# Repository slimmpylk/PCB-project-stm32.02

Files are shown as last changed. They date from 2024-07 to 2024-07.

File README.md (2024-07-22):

# Project Overview

The primary goal of this project was to intricately design the electronics and circuit board for a sophisticated embedded device. By harnessing our team's deep technical expertise, we set out to develop a high-end wireless weather station. This system is powered by the STM32WB microcontroller, renowned for its high performance and reliability in handling wireless communications.

## Implementation Details

Our team is committed to providing a comprehensive solution that not only measures various environmental parameters accurately but also facilitates efficient data transmission through wireless networks. At the heart of our design, the STM32WB microcontroller boasts Bluetooth capabilities, making it an excellent choice for our advanced weather monitoring system.

## Key Features

- **Real-Time Environmental Monitoring:** The station is capable of measuring temperature and humidity.
- **Energy-Efficient Design:** Focuses on low power consumption, ideal for long-term deployment in remote areas with minimal maintenance requirements.

This project is a testament to our team's dedication to pushing the boundaries of innovation and excellence in embedded systems design.

## Pics

# PCB
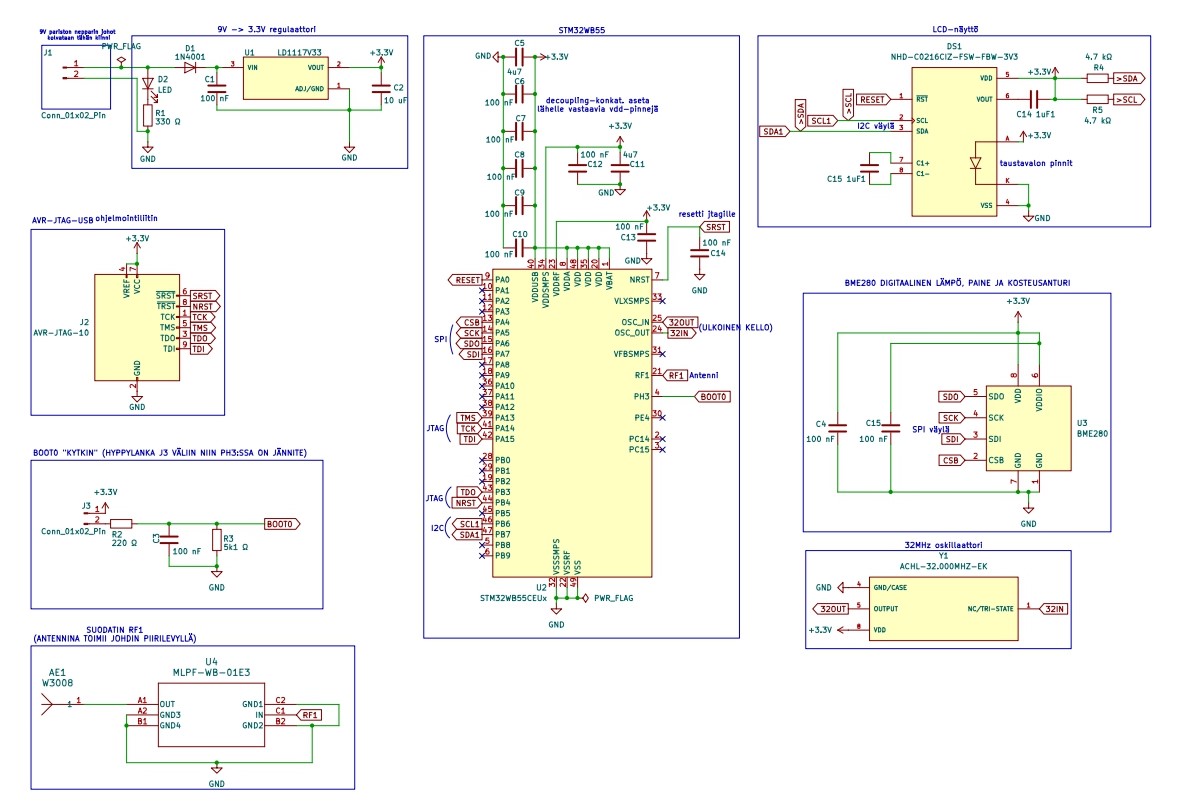
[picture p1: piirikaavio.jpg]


# PCB-schema
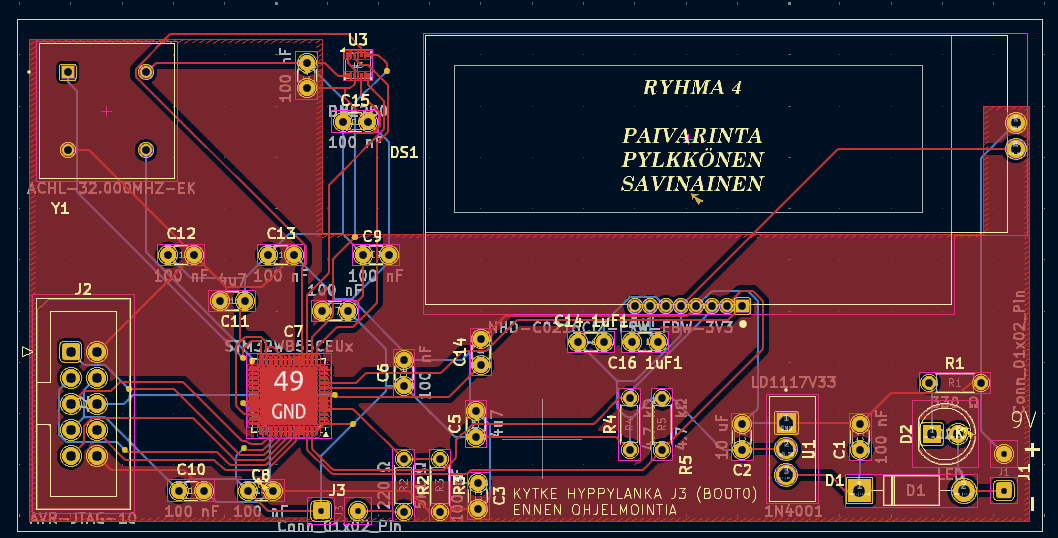
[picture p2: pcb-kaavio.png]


# 3D-pic
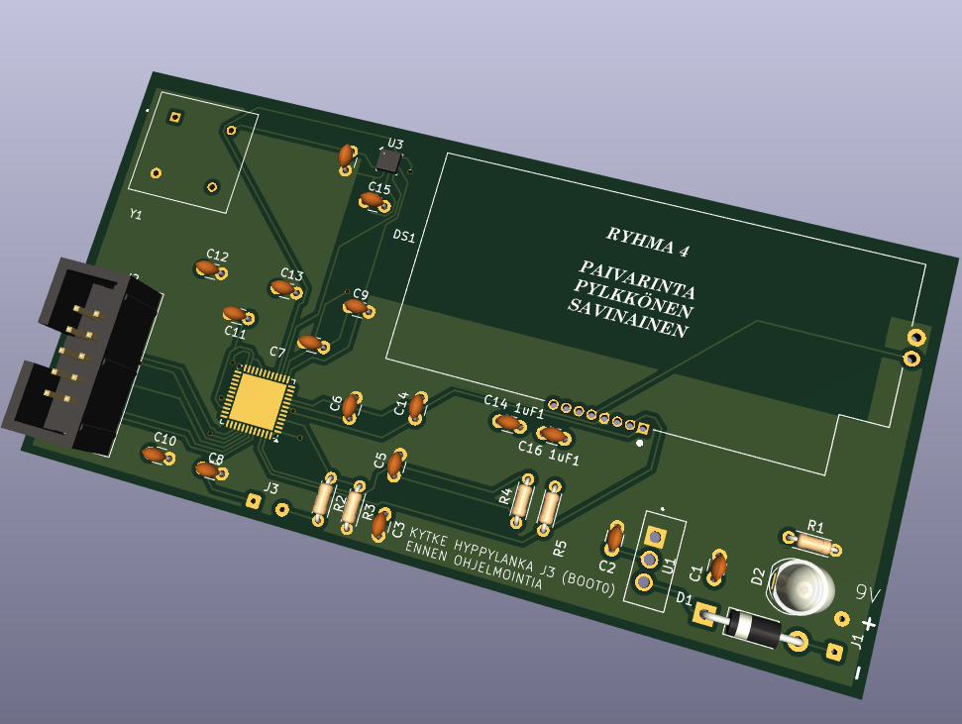
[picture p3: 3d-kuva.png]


# Built PCB
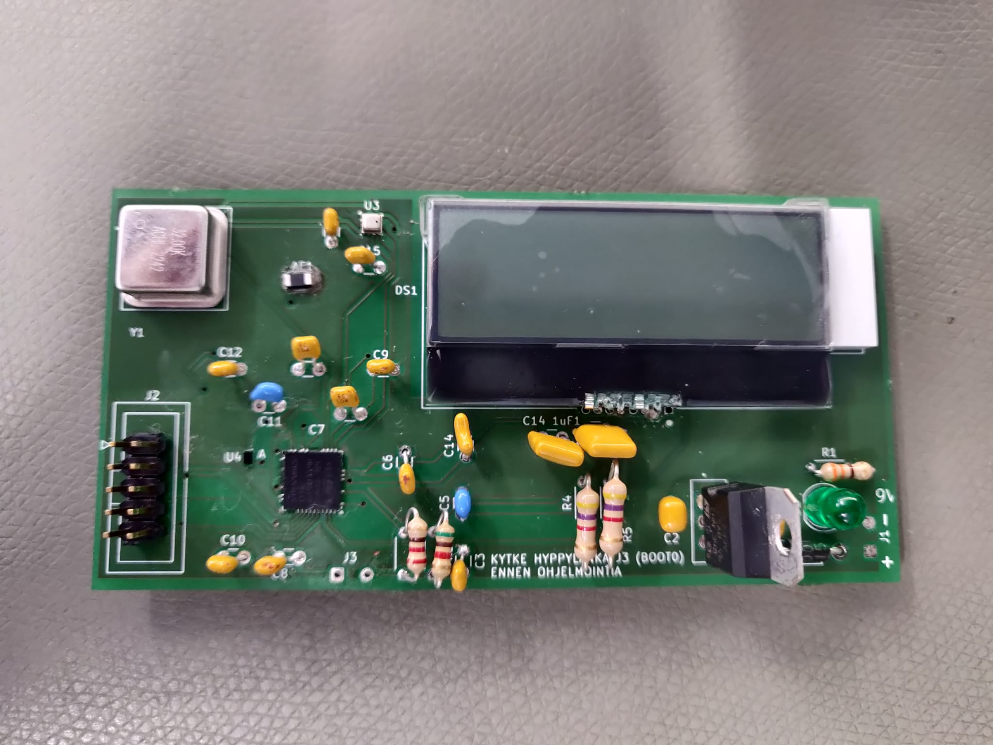
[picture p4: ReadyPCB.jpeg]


# STM close-up
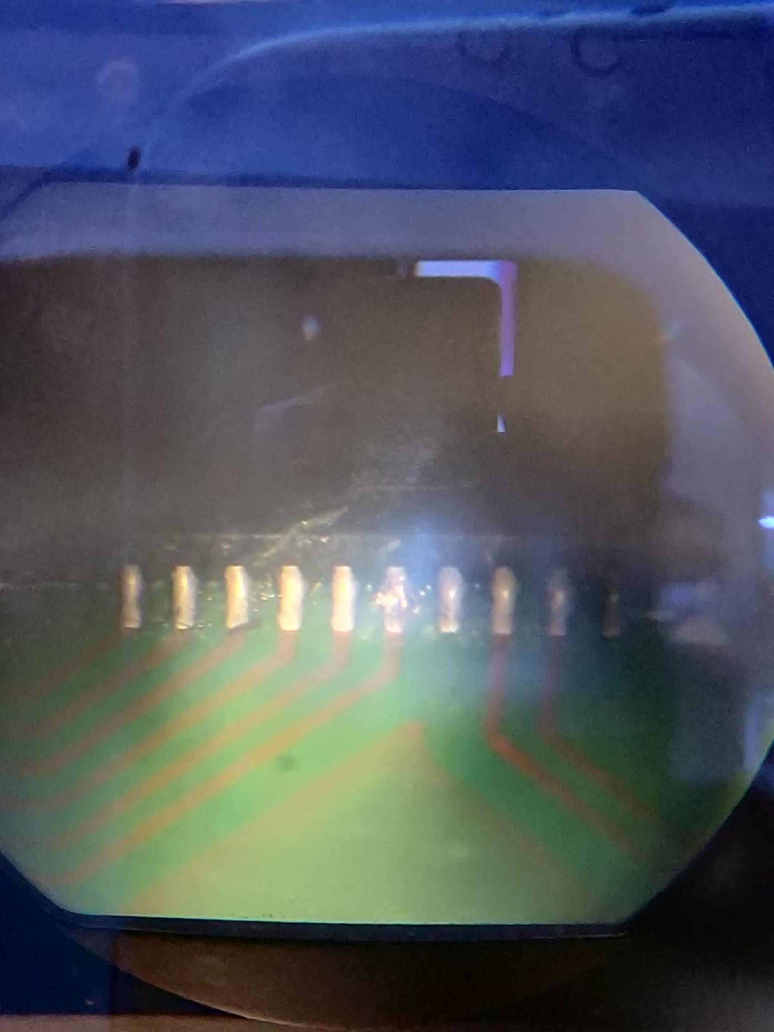
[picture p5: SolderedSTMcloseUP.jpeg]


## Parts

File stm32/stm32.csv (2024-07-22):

Source: | C:\Users\sammi\Desktop\kevätprojekti\Kevat24Proj\stm32\stm32.kicad_sch
Date: | 2024-04-04T11:24:38+0300
Tool: | Eeschema 8.0.1
Generator: | C:\Users\sammi\AppData\Local\Programs\KiCad\8.0\bin\scripting\plugins/bom_csv_grouped_by_value_with_fp.py
Component Count: | 34
Ref | Qnty | Value | Cmp name | Footprint | Description | Vendor | DNP
AE1 | 1 | W3008 | W3008 | footprints:ANT_W3008_PUL
C1, C3, C4, C6, C7, C8, C9, C10, C12, C13, C14, C15 | 12 | 100 nF | C | Capacitor_THT:C_Disc_D3.0mm_W1.6mm_P2.50mm | Unpolarized capacitor
C2 | 1 | 10 uF | C | Capacitor_THT:C_Disc_D3.0mm_W1.6mm_P2.50mm | Unpolarized capacitor
C5, C11 | 2 | 4u7 | C | Capacitor_THT:C_Disc_D3.0mm_W1.6mm_P2.50mm | Unpolarized capacitor
C14 1uF1 | 1 | ~ | C | Capacitor_THT:C_Disc_D3.0mm_W1.6mm_P2.50mm | Unpolarized capacitor
C15 1uF1 | 1 | 1uF | C | Capacitor_THT:C_Disc_D3.0mm_W1.6mm_P2.50mm | Unpolarized capacitor
D1 | 1 | 1N4001 | 1N4001 | Diode_THT:D_DO-41_SOD81_P10.16mm_Horizontal | 50V 1A General Purpose Rectifier Diode, DO-41
D2 | 1 | LED | LED | LED_THT:LED_D5.0mm_Clear | Light emitting diode
DS1 | 1 | NHD-C0216CIZ-FSW-FBW-3V3 | NHD-C0216CIZ-FSW-FBW-3V3 | lcd:LCD_NHD-C0216CIZ-FSW-FBW-3V3 | Character Display FSTN Transflective 16Char x 2Line 8-Pin
J1, J3 | 2 | Conn_01x02_Pin | Conn_01x02_Pin | Connector_Wire:SolderWire-0.1sqmm_1x02_P3.6mm_D0.4mm_OD1mm | Generic connector, single row, 01x02, script generated
J2 | 1 | AVR-JTAG-10 | AVR-JTAG-10 | Connector_IDC:IDC-Header_2x05_P2.54mm_Vertical | Atmel 10-pin JTAG connector
R1 | 1 | 330 Ω | R | Resistor_THT:R_Axial_DIN0204_L3.6mm_D1.6mm_P5.08mm_Horizontal | Resistor
R2 | 1 | 220 Ω | R | Resistor_THT:R_Axial_DIN0204_L3.6mm_D1.6mm_P5.08mm_Horizontal | Resistor
R3 | 1 | 5k1 Ω | R | Resistor_THT:R_Axial_DIN0204_L3.6mm_D1.6mm_P5.08mm_Horizontal | Resistor
R4, R5 | 2 | 4.7 kΩ | R | Resistor_THT:R_Axial_DIN0204_L3.6mm_D1.6mm_P5.08mm_Horizontal | Resistor
U1 | 1 | LD1117V33 | LD1117V33 | rekulaattori:TO255P1020X450X1968-3
U2 | 1 | STM32WB55CEUx | STM32WB55CEUx | Package_DFN_QFN:QFN-48-1EP_7x7mm_P0.5mm_EP5.6x5.6mm | STMicroelectronics Arm Cortex-M4 MCU, 512KB flash, 256KB RAM, 64 MHz, 1.71-3.6V, 30 GPIO, UFQFPN48
U3 | 1 | BME280 | BME280 | Package_LGA:Bosch_LGA-8_2.5x2.5mm_P0.65mm_ClockwisePinNumbering | 3-in-1 sensor, humidity, pressure, temperature, I2C and SPI interface, 1.71-3.6V, LGA-8
U4 | 1 | MLPF-WB-01E3 | MLPF-WB-01E3 | lpf:CSP6_BUMPLESS_STM
Y1 | 1 | ACHL-32.000MHZ-EK | ACHL-32.000MHZ-EK | oskillaattori:XTAL_ACHL-32.000MHZ-EK

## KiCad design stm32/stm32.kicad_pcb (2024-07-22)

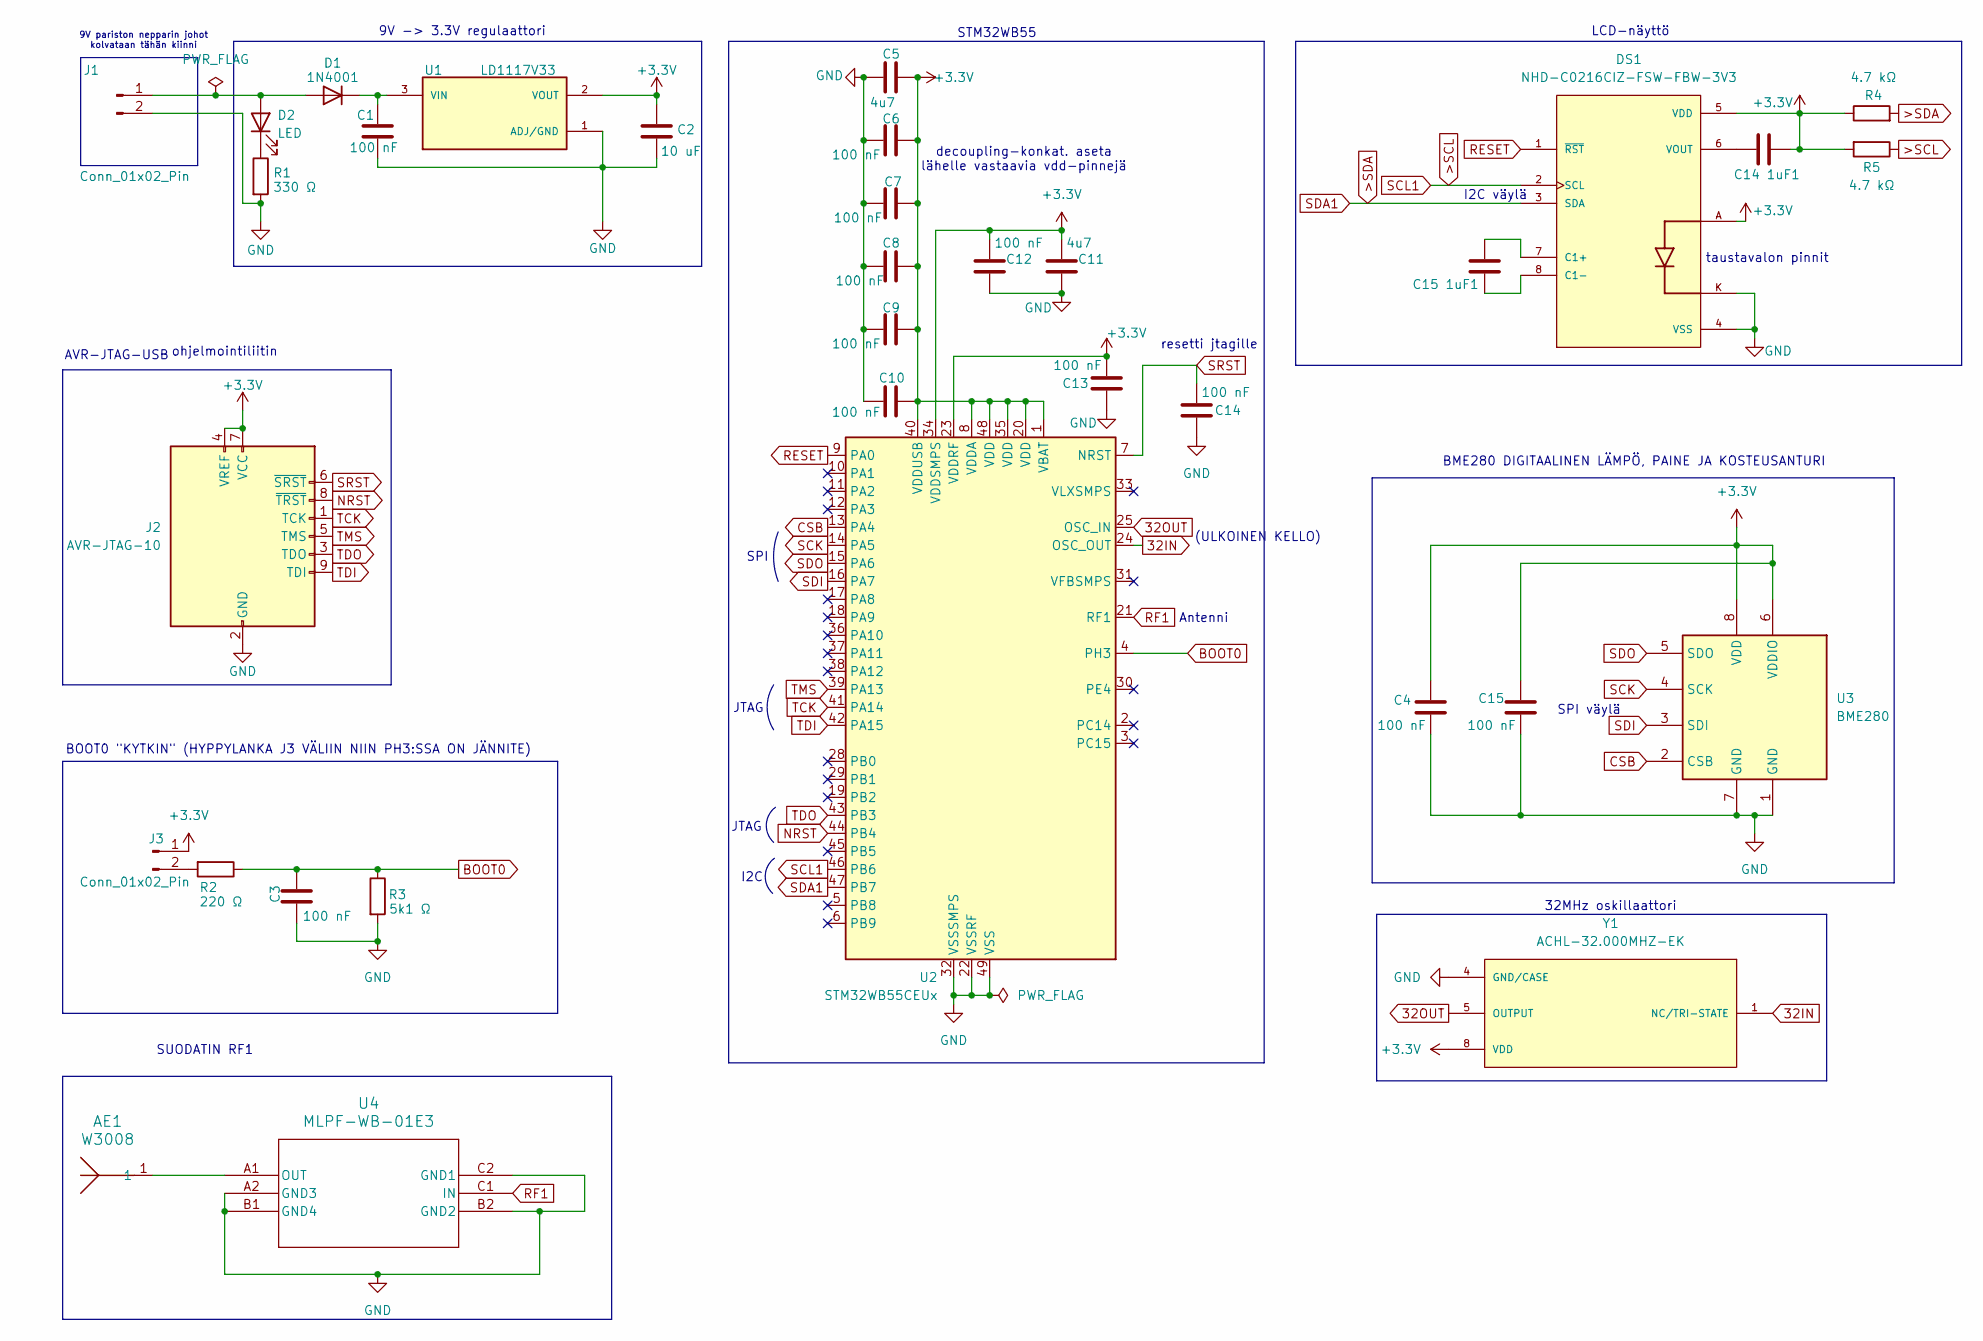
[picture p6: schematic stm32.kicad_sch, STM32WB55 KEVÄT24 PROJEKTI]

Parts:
AE1: W3008; ANT_W3008_PUL
C1, C3, C4, C6, C7, C8, C9, C10, C12, C13, C14, C15: 100 nF; C_Disc_D3.0mm_W1.6mm_P2.50mm
C2: 10 uF; C_Disc_D3.0mm_W1.6mm_P2.50mm
C5, C11: 4u7; C_Disc_D3.0mm_W1.6mm_P2.50mm
C14 1uF1: C_Disc_D3.0mm_W1.6mm_P2.50mm
C15 1uF1: 1uF; C_Disc_D3.0mm_W1.6mm_P2.50mm
D1: 1N4001; D_DO-41_SOD81_P10.16mm_Horizontal
D2: LED; LED_D5.0mm_Clear
DS1: NHD-C0216CIZ-FSW-FBW-3V3; LCD_NHD-C0216CIZ-FSW-FBW-3V3; PARTREV 6/4/19
J1, J3: Conn_01x02_Pin; SolderWire-0.1sqmm_1x02_P3.6mm_D0.4mm_OD1mm
J2: AVR-JTAG-10; IDC-Header_2x05_P2.54mm_Vertical
R1: 330 Ω; R_Axial_DIN0204_L3.6mm_D1.6mm_P5.08mm_Horizontal
R2: 220 Ω; R_Axial_DIN0204_L3.6mm_D1.6mm_P5.08mm_Horizontal
R3: 5k1 Ω; R_Axial_DIN0204_L3.6mm_D1.6mm_P5.08mm_Horizontal
R4, R5: 4.7 kΩ; R_Axial_DIN0204_L3.6mm_D1.6mm_P5.08mm_Horizontal
U1: LD1117V33; TO255P1020X450X1968-3; PARTREV 37
U2: STM32WB55CEUx; QFN-48-1EP_7x7mm_P0.5mm_EP5.6x5.6mm
U3: BME280; Bosch_LGA-8_2.5x2.5mm_P0.65mm_ClockwisePinNumbering
U4: MLPF-WB-01E3; CSP6_BUMPLESS_STM
Y1: ACHL-32.000MHZ-EK; XTAL_ACHL-32.000MHZ-EK; PARTREV 01.20.16

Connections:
32IN: U2.24 (OSC_OUT), Y1.1 (NC/TRI-STATE)
32OUT: U2.25 (OSC_IN), Y1.5 (OUTPUT)
+3.3V: C2.1, C4.1, C5.1, C6.1, C7.1, C8.1, C9.1, C10.1, C11.1, C12.1, C13.1, C14 1uF1.1, C15.1, DS1.5 (VDD), DS1.A, J2.4 (VREF), J2.7 (VCC), J3.1, R4.1, R5.2, U1.2 (VOUT), U2.1 (VBAT), U2.8 (VDDA), U2.20 (VDD), U2.23 (VDDRF), U2.34 (VDDSMPS), U2.35 (VDD), U2.40 (VDDUSB), U2.48 (VDD), U3.6 (VDDIO), U3.8 (VDD), Y1.8 (VDD)
>SCL: DS1.2 (SCL), R5.1, U2.46 (PB6)
>SDA: DS1.3 (SDA), R4.2, U2.47 (PB7)
BOOT0: C3.1, R2.1, R3.1, U2.4 (PH3)
CSB: U2.13 (PA4), U3.2 (CSB)
GND: C1.2, C2.2, C3.2, C4.2, C5.2, C6.2, C7.2, C8.2, C9.2, C10.2, C11.2, C12.2, C13.2, C14.2, C15.2, DS1.4 (VSS), DS1.K, J1.2, J2.2 (GND), J2.10 (GND), R1.2, R3.2, U1.1 (ADJ/GND), U2.22 (VSSRF), U2.32 (VSSSMPS), U2.49 (VSS), U3.1 (GND), U3.7 (GND), U4.A2 (GND3), U4.B1 (GND4), U4.B2 (GND2), U4.C2 (GND1), Y1.4 (GND/CASE)
NRST: J2.8 (~TRST), U2.44 (PB4)
unnamed: D1.2 (A), D2.2 (A), J1.1
unnamed: C1.1, D1.1 (K), U1.3 (VIN)
unnamed: D2.1 (K), R1.1
unnamed: C15 1uF1.1, DS1.7 (C1+)
unnamed: C15 1uF1.2, DS1.8 (C1-)
unnamed: C14 1uF1.2, DS1.6 (VOUT)
unnamed: J3.2, R2.2
unnamed: AE1.1, U4.A1 (OUT)
RESET: DS1.1 (~RST), U2.9 (PA0)
RF1: U2.21 (RF1), U4.C1 (IN)
SCK: U2.14 (PA5), U3.4 (SCK)
SDI: U2.16 (PA7), U3.3 (SDI)
SDO: U2.15 (PA6), U3.5 (SDO)
SRST: C14.1, J2.6 (~SRST), U2.7 (NRST)
TCK: J2.1 (TCK), U2.41 (PA14)
TDI: J2.9 (TDI), U2.42 (PA15)
TDO: J2.3 (TDO), U2.43 (PB3)
TMS: J2.5 (TMS), U2.39 (PA13)

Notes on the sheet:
BME280 DIGITAALINEN LÄMPÖ, PAINE JA KOSTEUSANTURI
STM32WB55
Antenni
resetti jtagille
I2C väylä
decoupling-konkat. aseta lähelle vastaavia vdd-pinnejä
9V pariston nepparin johot kolvataan tähän kiinni
BOOT0 "KYTKIN" (HYPPYLANKA J3 VÄLIIN NIIN PH3:SSA ON JÄNNITE)
9V -> 3.3V regulaattori
JTAG
32MHz oskillaattori
AVR-JTAG-USB
I2C
SUODATIN RF1
(ULKOINEN KELLO)
LCD-näyttö
taustavalon pinnit
ohjelmointiliitin
SPI väylä
SPI

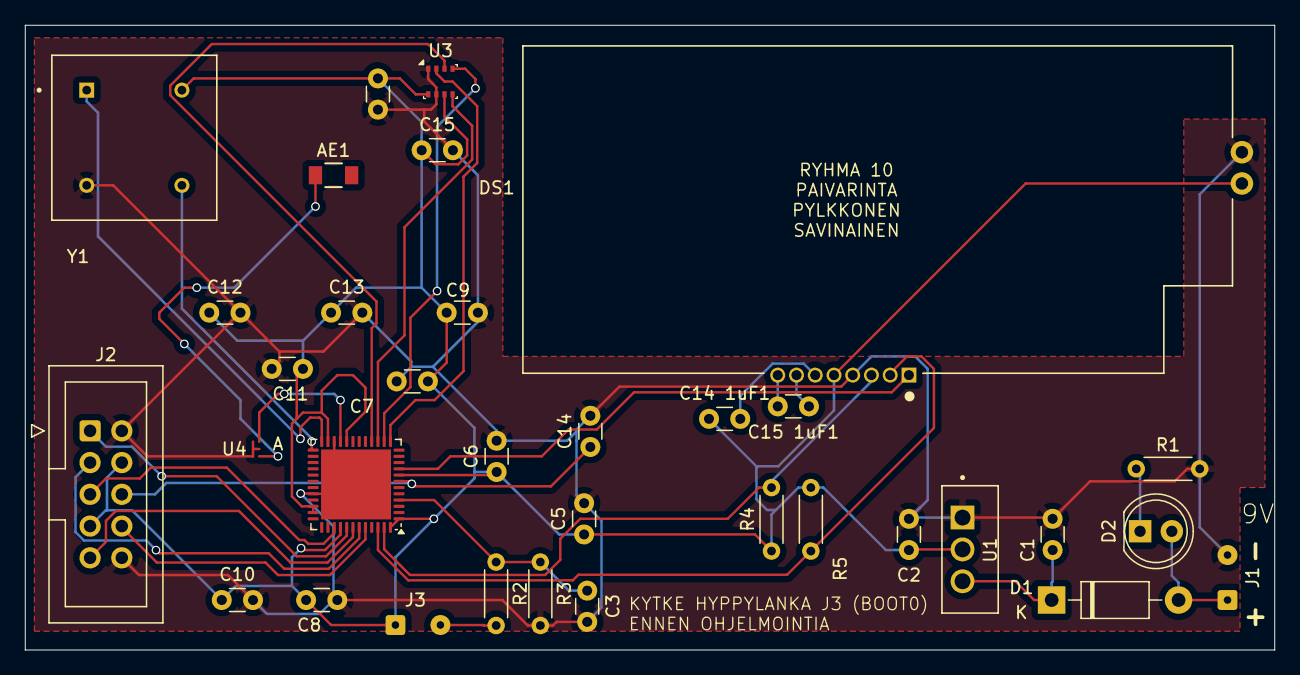
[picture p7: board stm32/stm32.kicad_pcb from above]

Board: 2 copper layers, 100.0 x 50.0 mm, 34 parts (0 on the bottom side), 27 nets.

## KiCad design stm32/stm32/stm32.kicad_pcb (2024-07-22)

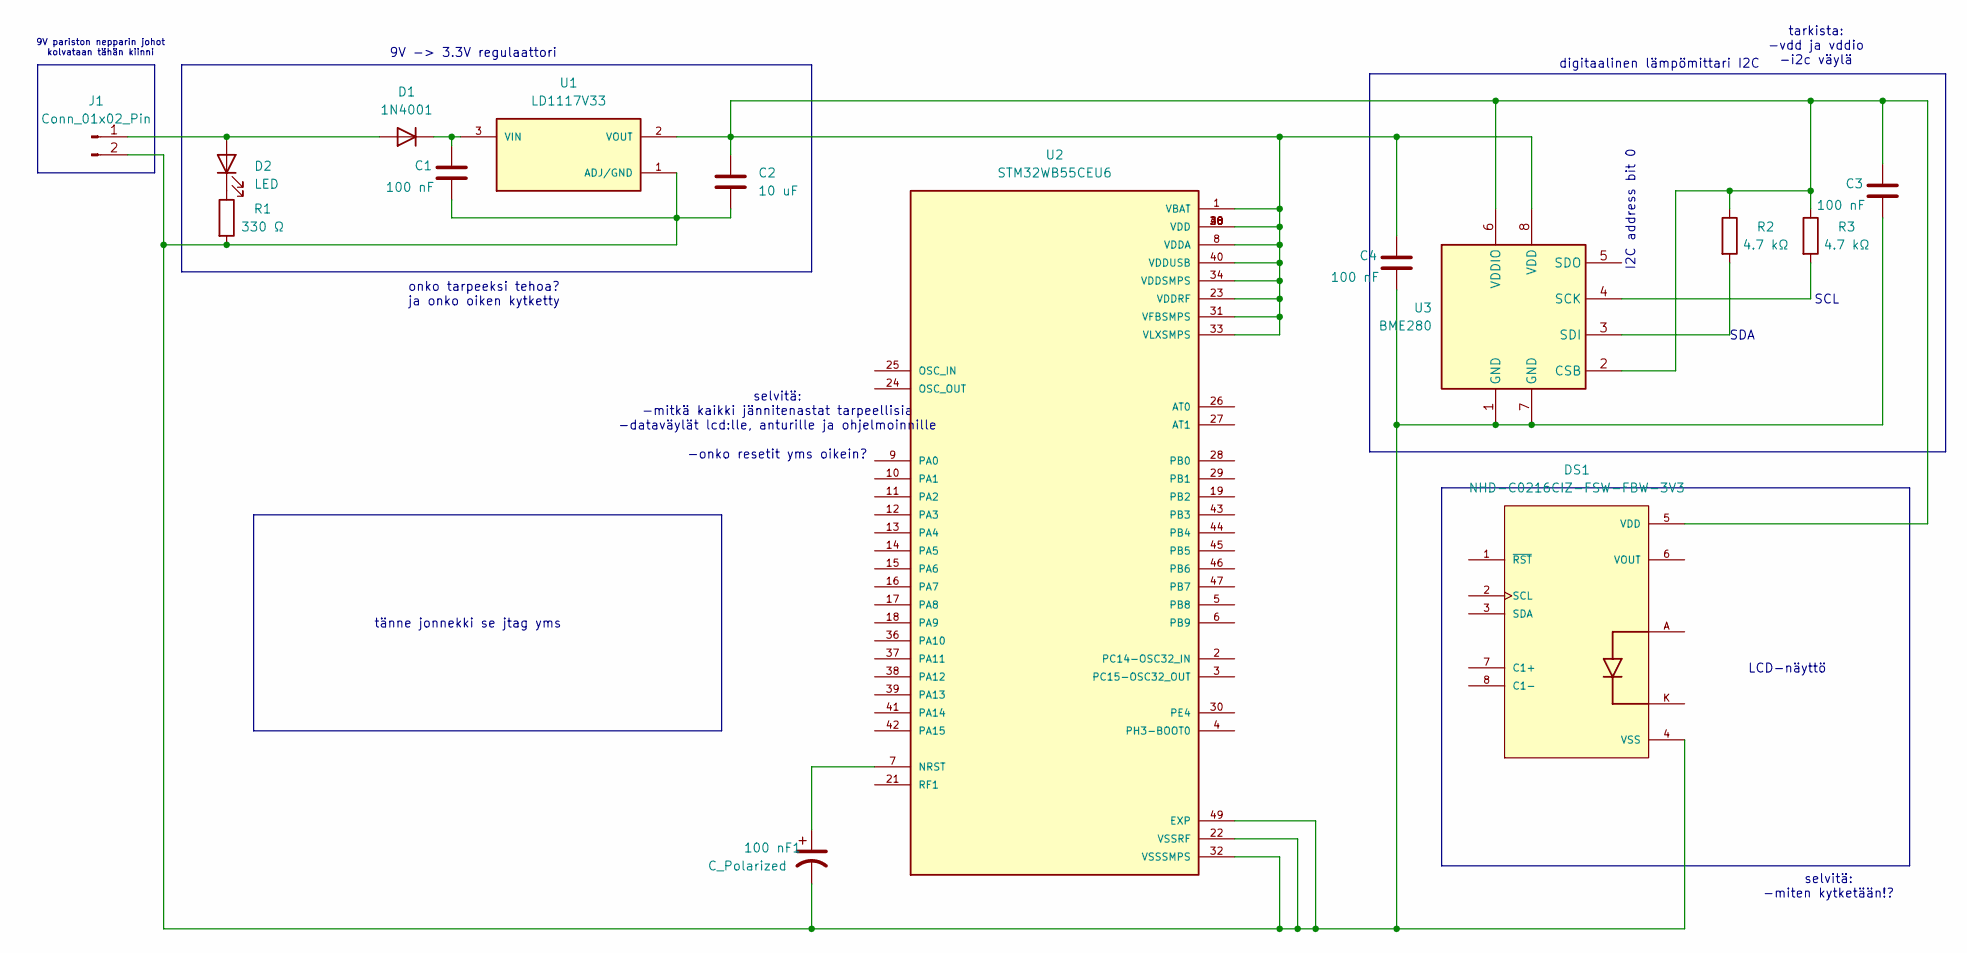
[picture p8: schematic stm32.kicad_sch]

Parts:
100 nF1: C_Polarized; CP_Elec_3x5.3
C1, C3, C4: 100 nF; C_Elec_3x5.4
C2: 10 uF; C_Elec_3x5.4
D1: 1N4001; D_DO-41_SOD81_P10.16mm_Horizontal
D2: LED; LED_D5.0mm_Clear
DS1: NHD-C0216CIZ-FSW-FBW-3V3; LCD_NHD-C0216CIZ-FSW-FBW-3V3; PARTREV 6/4/19
J1: Conn_01x02_Pin; SolderWire-0.1sqmm_1x02_P3.6mm_D0.4mm_OD1mm
R1: 330 Ω; R_Axial_DIN0204_L3.6mm_D1.6mm_P5.08mm_Horizontal
R2, R3: 4.7 kΩ; R_Axial_DIN0204_L3.6mm_D1.6mm_P5.08mm_Horizontal
U1: LD1117V33; TO255P1020X450X1968-3; PARTREV 37
U2: STM32WB55CEU6; QFN50P700X700X60-49N; PARTREV 5
U3: BME280; Bosch_LGA-8_2.5x2.5mm_P0.65mm_ClockwisePinNumbering

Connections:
unnamed: D1.2 (A), D2.2 (A), J1.1
unnamed: C1.1, D1.1 (K), U1.3 (VIN)
unnamed: D2.1 (K), R1.1
unnamed: C2.1, C3.1, C4.1, DS1.5 (VDD), R2.1, R3.1, U1.2 (VOUT), U2.1 (VBAT), U2.8 (VDDA), U2.20 (VDD), U2.23 (VDDRF), U2.31 (VFBSMPS), U2.33 (VLXSMPS), U2.34 (VDDSMPS), U2.35 (VDD), U2.40 (VDDUSB), U2.48 (VDD), U3.2 (CSB), U3.6 (VDDIO), U3.8 (VDD)
unnamed: 100 nF1.2, C1.2, C2.2, C3.2, C4.2, DS1.4 (VSS), J1.2, R1.2, U1.1 (ADJ/GND), U2.22 (VSSRF), U2.32 (VSSSMPS), U2.49 (EXP), U3.1 (GND), U3.7 (GND)
unnamed: 100 nF1.1, U2.7 (NRST)
unnamed: R3.2, U3.4 (SCK)
unnamed: R2.2, U3.3 (SDI)

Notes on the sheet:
SDA
tarkista: -vdd ja vddio -i2c väylä
selvitä: -mitkä kaikki jännitenastat tarpeellisia -dataväylät lcd:lle, anturille ja ohjelmoinnille -onko resetit yms oikein?
onko tarpeeksi tehoa? ja onko oiken kytketty
selvitä: -miten kytketään!?
I2C address bit 0
9V pariston nepparin johot kolvataan tähän kiinni
SCL
tänne jonnekki se jtag yms
LCD-näyttö
digitaalinen lämpömittari I2C
9V -> 3.3V regulaattori

Board: 2 copper layers, 15 parts (0 on the bottom side), 8 nets, no tracks yet.

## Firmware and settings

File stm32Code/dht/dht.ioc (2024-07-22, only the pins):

Mcu.UserName=STM32F411RETx
PA1.Signal=GPIO_Output
PA13.GPIO_Label=TMS
PA13.Signal=SYS_JTMS-SWDIO
PA14.GPIO_Label=TCK
PA14.Signal=SYS_JTCK-SWCLK
PA2.GPIO_Label=USART_TX
PA2.Signal=USART2_TX
PA3.GPIO_Label=USART_RX
PA3.Signal=USART2_RX
PA5.GPIO_Label=LD2 [Green Led]
PA5.Signal=GPIO_Output
PB3.GPIO_Label=SWO
PB3.Signal=SYS_JTDO-SWO
PC13-ANTI_TAMP.GPIO_Label=B1 [Blue PushButton]
PC13-ANTI_TAMP.Signal=GPXTI13
PC14-OSC32_IN.Signal=RCC_OSC32_IN
PC15-OSC32_OUT.Signal=RCC_OSC32_OUT
